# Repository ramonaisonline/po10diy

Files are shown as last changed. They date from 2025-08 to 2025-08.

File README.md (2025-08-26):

# po10diy
A tiny video synthesizer in the pocket operator format

## Background
I made this for the Teenage Engineering #po10diy contest — it's a two-color video synthesizer that has an onboard screen and battery for making video art on the go, and a DVI port so you can plug it into a projector!

You can read the full story behind it on my website: [ramona.diy](https://ramona.diy/video-art/po-video)

## Making your own
I'm not selling these, but this repository includes everything you'd need to make your own! And I encourage that! Please send me pics :)

# Hardware
## Supplies
I estimate that these cost around $100 to build. The most expensive parts of this are:
- The display ($45)
- The microcontroller ($15)
- The PCB (maybe $10-20 depending on where you get it from, how many you order, the tariffs du jour, etc).

### Parts
- 1 x [Adafruit Feather RP2040 with DVI](https://www.adafruit.com/product/5710)
- 1 x [Adafruit 2.7” 400x240 Sharp Memory Display](https://www.adafruit.com/product/4694)
- 2 x [10k potentiometer with built-in knob](https://www.adafruit.com/product/4133)
- 2 x [Breadboard-friendly 3.5mm stereo headphone jack](https://www.adafruit.com/product/1699)
- 1 x [Adafruit 400 mAh LiPo battery](https://www.adafruit.com/product/3898)
- 18 x [Surface-mount tactile switches](https://www.jameco.com/z/TL3301NF160QG-TR-JVP-Jameco-ValuePro-Surface-Mount-Tactile-Pushbutton-Switch-SPST-NO-OFF-MOM-50mA-12VDC-Tape-Reel_2334399.html)
- 18 x [Surface-mount 1N4148 diode](https://www.mouser.com/ProductDetail/Vishay/1N4148W-HG3_A-08?qs=Imq1NPwxi77PuyLGBhrVtQ%3D%3D)
- 2 x [Surface-mount 1.1k resistor](https://www.mouser.com/ProductDetail/Vishay-Beyschlag/MCS04020D1101BE000?qs=bTzheeSci6TjHr/d2PD0oQ%3D%3D)
  - R3 and R4 on the PCB
- 1 x [10.2k Surface-mount resistor](https://www.mouser.com/ProductDetail/Vishay/MCS04020D1022BE000?qs=pUKx8fyJudATYWOpd0Fc/A%3D%3D)
  - R1 on the PCB
- 1 x [15k Surface-mount resistor](https://www.mouser.com/ProductDetail/Vishay-Beyschlag/MCS04020C1502FE500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)
  - R2 on the PCB
- 2 x [15 uF Surface-mount capacitor](https://www.mouser.com/ProductDetail/Murata-Electronics/GRM155R60G156ME01D?qs=doiCPypUmgFLObzcgpnt9Q%3D%3D)
  - C1 and C2 on the PCB
- 1 x [Slide switch](https://www.mouser.com/ProductDetail/E-Switch/EGJ1210AAT2?qs=%252BXxaIXUDbq28DPumZsnIIA%3D%3D)
- Standard 0.1” header pins and sockets, specifically:
  - One 12-pin female header
  - One 12-pin male header
  - One 16-pin female header
  - One 16-pin male header
  - One 9-pin male header (for the display)
  - You can buy these in bulk (I just had a bunch lying around), or you can get some from Adafruit, like [this](https://www.adafruit.com/product/2886) and [this](https://www.adafruit.com/product/3002)
- Custom PCB
  - I've uploaded the files for these too, so you can just order them directly
  - More details below
- 4 x M2 or M2.5 10mm machine screw
- 12 x M2 or M2.5 nut

### Tools
- Soldering iron
- Lead-free solder
- Low-temp solder paste
  - I used [Maker Paste](https://www.adafruit.com/product/3217)
- Hot plate
  - I used a TLBZK 100mm x 100mm 350W hot plate from Amazon
- Ventilation fan
- Snips
- Tweezers for positioning small components
- Hobby knife or file for cleaning up rough PCB edges

## PCB
You can order the board from [my shared project on OSHPark](https://oshpark.com/shared_projects/P2hzrhho) — as of August 2025 it costs $61 for 3 copies.

If you'd prefer to order them from a different manufacturer, you can use the exported Gerber files in the PCB Files directory. I believe the existing exports will just work, but if they don't for whatever reason, I've also included the entire KiCAD project. You can find [instructions for exporting the files yourself here](https://jlcpcb.com/help/article/how-to-generate-gerber-and-drill-files-in-kicad-8) (for JLCPCB at least).

## Assembly steps

### 1. Cut or file down any rough edges on the PCB
- Mine came with little spiky protrusions from the manufacturing process, and I just snipped and filed them down

### 2. Unpackage and organize your parts
- The resistors especially are hard to tell apart, so keep everything nice and tidy and don't forget what's what!

### 3. Place the surface-mount diodes, resistors, and capcitors
- Pre-heat the hotplate according to your solder paste (I used Maker Paste and set my hotplate to 145 C)
- Squeeze out little dabs of maker paste on each of the pads for the diodes, resistors, and capacitors (we'll do the tactile switches in a separate step)
  - Some of these pads are quite small, so it can help to use a toothpick to scrape out little blobs of paste and wipe them where you want them, rather than squeezing from the tube directly onto the PCB
- Use small amounts of paste, and be especially cautious with the pads for the tiny resistors and capacitors, as they can easily form bridges when too much solder paste is used
- Use tweezers to position the diodes, resistors, and capacitors into their respective places one by one, and gently press them into the paste
  - R1 is the 10.2k resistor
  - R2 is the 15k resistor
  - R3 and R4 are the 1.1k resistors
  - The capacitors are identical but go in the spots marked C1 and C2
  - The diodes are also interchangeable but make sure the stripe on the diode is facing INTO the "C" shaped silkscreen marking, not away from it

### 4. Solder the diodes, resistors, and capacitors
- With the components all placed, put the PCB on the hotplate and let it melt the solder
- First you'll see the paste blobs spread out as the paste warms
- Then the liquid-y flux will boil off
- Then the solder balls in the paste will melt and reflow onto the pads, hopefully avoiding the solder mask
- This process takes a minute or two depending on the temperature
- Ideally you should see your components slide and adjust into place from the surface tension of the solder
- Watch carefully to make sure the solder paste is all melting at roughly the same time
  - If the board isn't sitting totally flat, press it down with a scredriver or tweezers to make sure it's heating evenly
- Look for any solder bridges that might have formed around the smallest components, and use tweezers or a craft knife to very gently remove some of the solder or smush it around until it separates again from the solder mask

### 5. Let the PCB cool
- It will be quite hot, so remove the PCB with tweezers or something similar and let it cool down and rest on a heat-safe surface
- Let it cool completely, to make the next step easier

### 6. Place the tactile switches
- Make sure the hot plate is preheating again if you shut it off earlier
- Like before, squeeze out solder blobs onto all the pads of the 18 tactile switches (though this time it will be a little easier to not make a mess since the pads are larger and further apart)
- Use tweezers to position the tactile switches on the blobs of solder paste

### 7. Solder the tactile switches
- Like before, put the PCB on the hotplate
  - I tried to have the top third of the PCB hanging off the plate so that the smaller components didn't heat up again, just in case their positioning got messed up, but I don't know how much of a difference this makes
- Wait a minute or two for the paste to melt and attach the switches

### 8. Let the PCB cool
- It's hot! Be careful!

### 9. Flip the board over and solder the 12 and 16 pin female header strips to the underside of the board
- The microcontroller will go on the back
- Strictly speaking you don't need the female header here, you could solder the feather to the circuit board directly with male header, but the female header makes it removable in case you want to use it for something else later, and it makes room for the battery to go underneath
- Trim the leads if they're long on the front side, the display will go above them and there's only so much room

### 10. Solder the 12 and 16 pin male header strips to the Feather
- The header should point "down" (i.e. the longer part should protrude from the flat bottom of the Feather), and you should be soldering it from the top of the Feather
- I like to just plug the male header into the female header we just soldered, then drop the Feather on top of that and solder — it holds everything in place!

### 11. Solder the audio jacks to the back of the board
- You may have to press quite firmly to get all five pins to slide into the holes at once, or even bend them a bit to align better

### 12. Solder the slide switch to the front of the board
- It's slim enough to fit under the display, so you can mount it on the front
- Note that when I designed the PCB I hooked up this switch backwards, so you slide it "down" / towards you to turn it on

### 13. Solder the potentiometers
- You may have to bend the side tabs in slightly to get them to align with the holes
- Double check the tilt of the potentiometers by looking at them from the side. It's easy for them to slightly lean one direction or the other.

### 14. At this point, you can test!
- Upload the code to the Feather using the procedure below to test the device with an external projector / monitor / TV and verify that the buttons and pots all work as expected
- This step is optional, but it's much easier to fix any issues with the diodes / resisotrs / capacitors now, before you solder the display on
- At a minimum, check the connections with a thorough visual inspection and maybe even with a multimeter
- Make sure there are no shorts from excess solder, and that all the components are fully and securely attached

### 15. Solder the male header to the display
- But do NOT solder it to rest of the PCB yet! That will be our final step because it depends on a few things being aligned first.

### 16. File down the right inner corner of the display to fit around Pot B
- Note that the lower mounting points of the display have a slight inner radius where they meet the main body of the display PCB
- This will bump into the hard corner of Pot B and make it hard to align the display properly
- With a craft knife or a file, you can shave down that inner corner radius to a right angle
- You may also need to file down the part of plastic casing of the potentiometers that faces the display a bit to get it to slide smoothly past them

### 17. Mount the display
- Thread bolts through the four mounting holes of the display
- If using M2 bolts, thread two nuts on each of the bolts to provide even spacing between the display and the main PCB
- If using M2.5 bolts, thread nuts only on the upper left, upper right, and lower left bolts (the nuts are too big to sit next to the pots)
- Mount the display to the main PCB using four more nuts
  - The already-soldered male header should be poking through the holes on the main PCB now

### 18. Solder the display
- Almost done! You can test it now if you Like

### 19. Install the battery
- Now, you can plug in the LiPo battery and tuck it under the feather
- It helps to secure it with a piece of tape or something like that

# Software
I've included the Arduino code that I used on my version, with all the drawing functions and everything. Feel free to modify it to your liking! I've included a template layer function in the layers.ino file along with some instructions about how to use the buttons / pot values / etc.

## Flashing the Feather
I recommend follow Adafruit's detailed setup steps:
- [Setting up the Arduino IDE for RP2040 boards](https://learn.adafruit.com/adafruit-feather-rp2040-dvi/arduino-ide-setup)
- [Loading sketches onto the Feather RP2040](https://learn.adafruit.com/adafruit-feather-rp2040-dvi/arduino-usage)
  - The Feather has a UF2 bootloader which means it should be able to put itself into a special mode where it acts as a USB drive and the Arduino IDE can just drop a file on it to load the compiled sketch -- you SHOULD be able to just click "Upload" in the Arduino IDE and it should just work
  - However, I've never gotten that to work consistently, for whatever reason
  - Instead I follow the manual bootloader steps at the bottom of that page, and it works very reliably
  - That does make it slightly more annoying to use the serial monitor because sometimes you have to switch the selected board in the Arduino IDE and close / open the serial monitor panel to get messages to come through
  - All that is to say, YMMV, and try it both ways!
- [All about the PicoDVI library for the Feather](https://learn.adafruit.com/picodvi-arduino-library-video-out-for-rp2040-boards)
- [Drawing shapes with Adafruit GFX](https://learn.adafruit.com/adafruit-gfx-graphics-library/graphics-primitives)

## Remaining TODOs
A few small features left to implement here!
- The PO Sync feature (the PCB should be set up for it)
- Creating / swapping between different sequences (the folder button)
- Switch layers without triggering them via the layer buttons
- Change tempo

# Using it
TODO: Quick user manual

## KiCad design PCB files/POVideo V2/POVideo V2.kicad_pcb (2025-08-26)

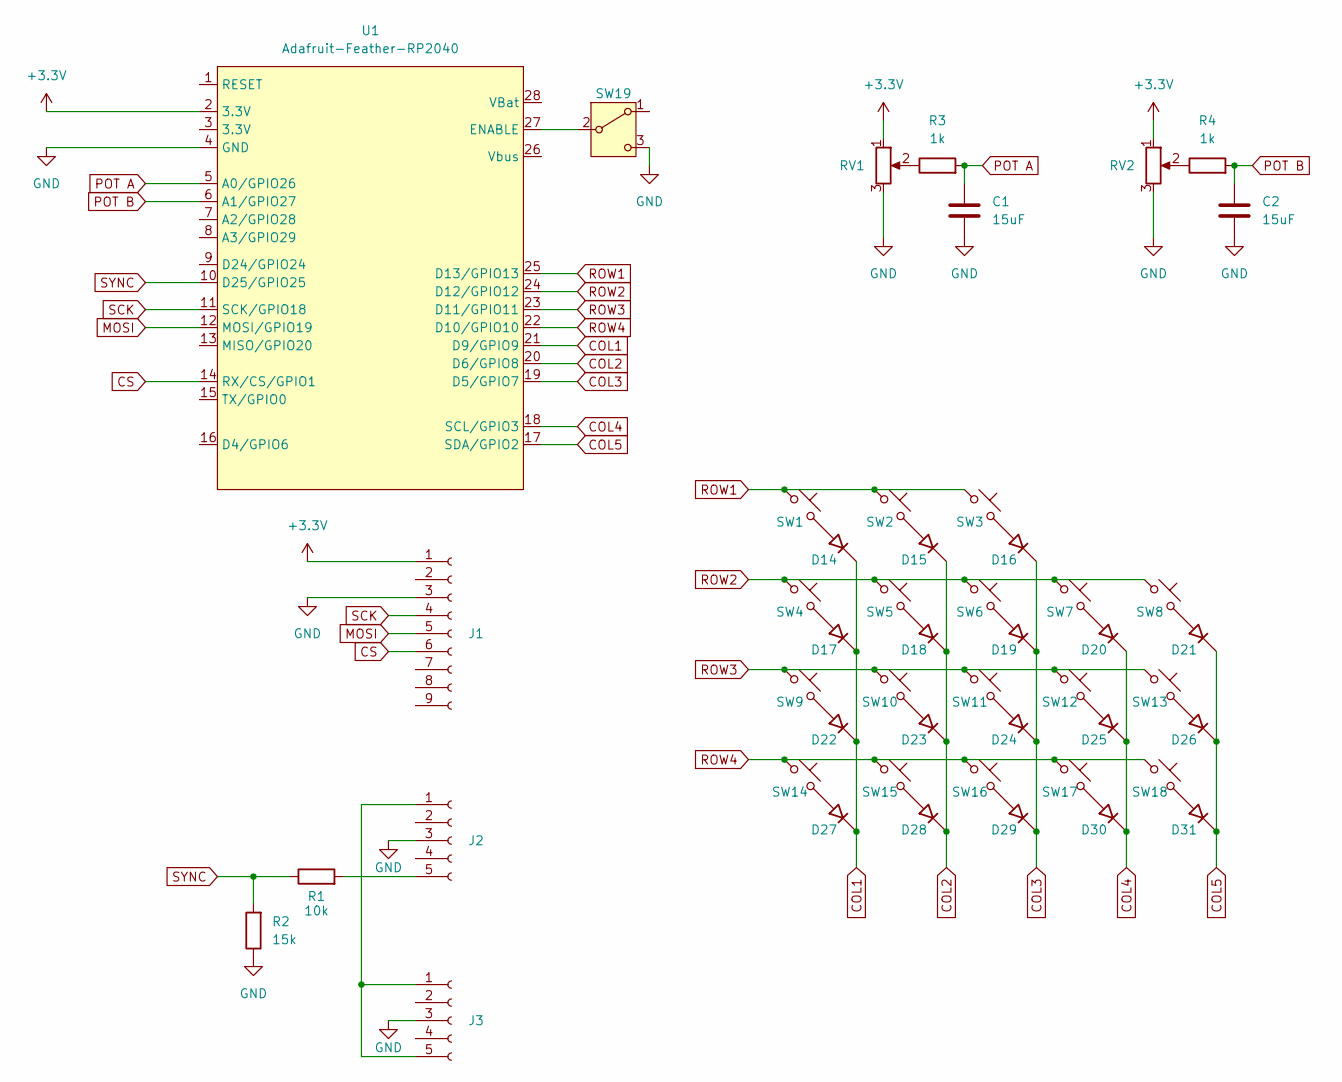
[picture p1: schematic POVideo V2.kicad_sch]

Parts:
C1, C2: 15uF; C_0402_1005Metric
D14, D15, D16, D17, D18, D19, D20, D21, D22, D23, D24, D25, D26, D27, D28, D29, D30, D31: D_45deg; D_SOD-123
J1: Conn_01x05_Socket; PinHeader_1x09_P2.54mm_Vertical
J2, J3: Conn_01x05_Socket; 5 pin headphone jack
R1: 10k; R_0402_1005Metric
R2: 15k; R_0402_1005Metric
R3, R4: 1k; R_0402_1005Metric
RV1, RV2: R_Potentiometer; Adafruit Potentiometer
SW1, SW2, SW3, SW4, SW5, SW6, SW7, SW8, SW9, SW10, SW11, SW12, SW13, SW14, SW15, SW16, SW17, SW18: SW_Push_45deg; TL3301 6mm tactile switch
SW19: SW_SPST; Right Angle Slide Switch
U1: Adafruit-Feather-RP2040; Adafruit_Feather

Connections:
+3.3V: J1.1, RV1.1, RV2.1, U1.2 (3.3V)
COL1: D14.1 (K), D17.1 (K), D22.1 (K), D27.1 (K), U1.21 (D9/GPIO9)
COL2: D15.1 (K), D18.1 (K), D23.1 (K), D28.1 (K), U1.20 (D6/GPIO8)
COL3: D16.1 (K), D19.1 (K), D24.1 (K), D29.1 (K), U1.19 (D5/GPIO7)
COL4: D20.1 (K), D25.1 (K), D30.1 (K), U1.18 (SCL/GPIO3)
COL5: D21.1 (K), D26.1 (K), D31.1 (K), U1.17 (SDA/GPIO2)
CS: J1.6, U1.14 (RX/CS/GPIO1)
GND: C1.2, C2.2, J1.3, J2.3, J3.3, R2.1, RV1.3, RV2.3, SW19.3 (C), U1.4 (GND)
LED_DATA: U1.16 (D4/GPIO6)
MOSI: J1.5, U1.12 (MOSI/GPIO19)
unnamed: D14.2 (A), SW1.2
unnamed: D15.2 (A), SW2.2
unnamed: D16.2 (A), SW3.2
unnamed: D17.2 (A), SW4.2
unnamed: D18.2 (A), SW5.2
unnamed: D19.2 (A), SW6.2
unnamed: D20.2 (A), SW7.2
unnamed: D21.2 (A), SW8.2
unnamed: D22.2 (A), SW9.2
unnamed: D23.2 (A), SW10.2
unnamed: D24.2 (A), SW11.2
unnamed: D25.2 (A), SW12.2
unnamed: D26.2 (A), SW13.2
unnamed: D27.2 (A), SW14.2
unnamed: D28.2 (A), SW15.2
unnamed: D29.2 (A), SW16.2
unnamed: D30.2 (A), SW17.2
unnamed: D31.2 (A), SW18.2
unnamed: J2.1, J3.1, J3.5
unnamed: J2.5, R1.2
unnamed: R3.1, RV1.2
unnamed: R4.1, RV2.2
unnamed: SW19.2 (B), U1.27 (ENABLE)
POT A: C1.1, R3.2, U1.5 (A0/GPIO26)
POT B: C2.1, R4.2, U1.6 (A1/GPIO27)
ROW1: SW1.1, SW2.1, SW3.1, U1.25 (D13/GPIO13)
ROW2: SW4.1, SW5.1, SW6.1, SW7.1, SW8.1, U1.24 (D12/GPIO12)
ROW3: SW9.1, SW10.1, SW11.1, SW12.1, SW13.1, U1.23 (D11/GPIO11)
ROW4: SW14.1, SW15.1, SW16.1, SW17.1, SW18.1, U1.22 (D10/GPIO10)
SCK: J1.4, U1.11 (SCK/GPIO18)
SYNC: R1.1, R2.2, U1.10 (D25/GPIO25)

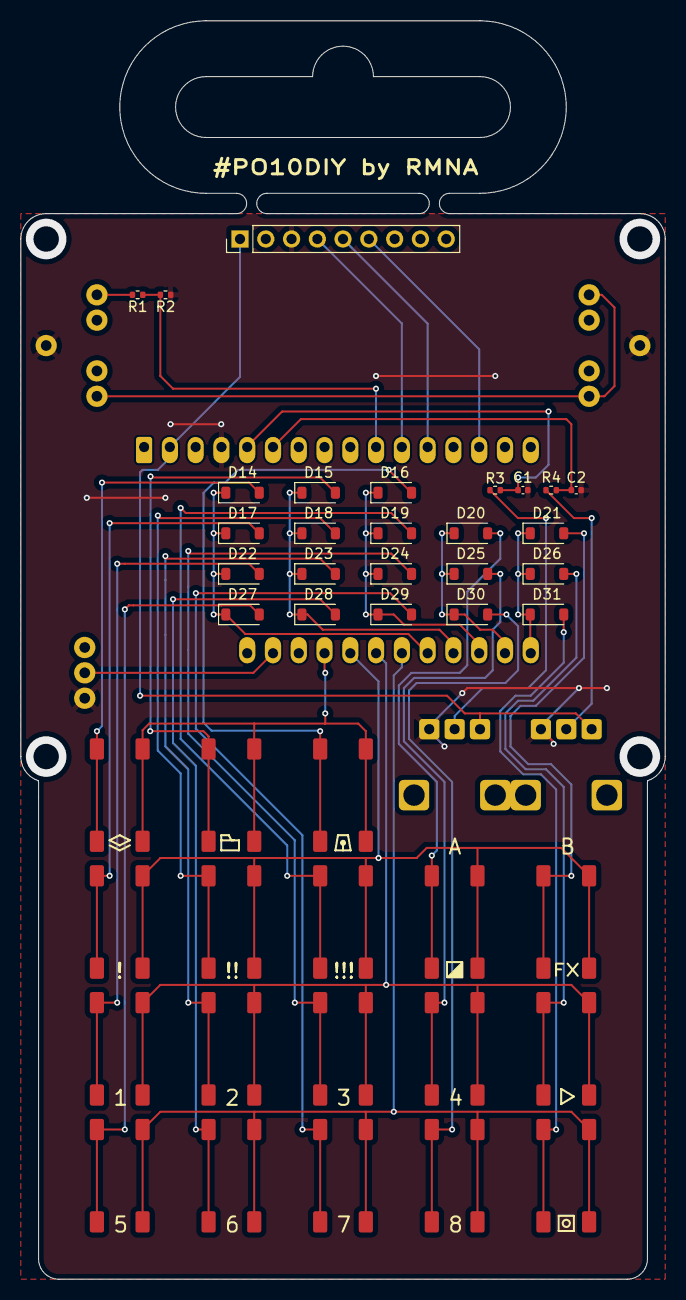
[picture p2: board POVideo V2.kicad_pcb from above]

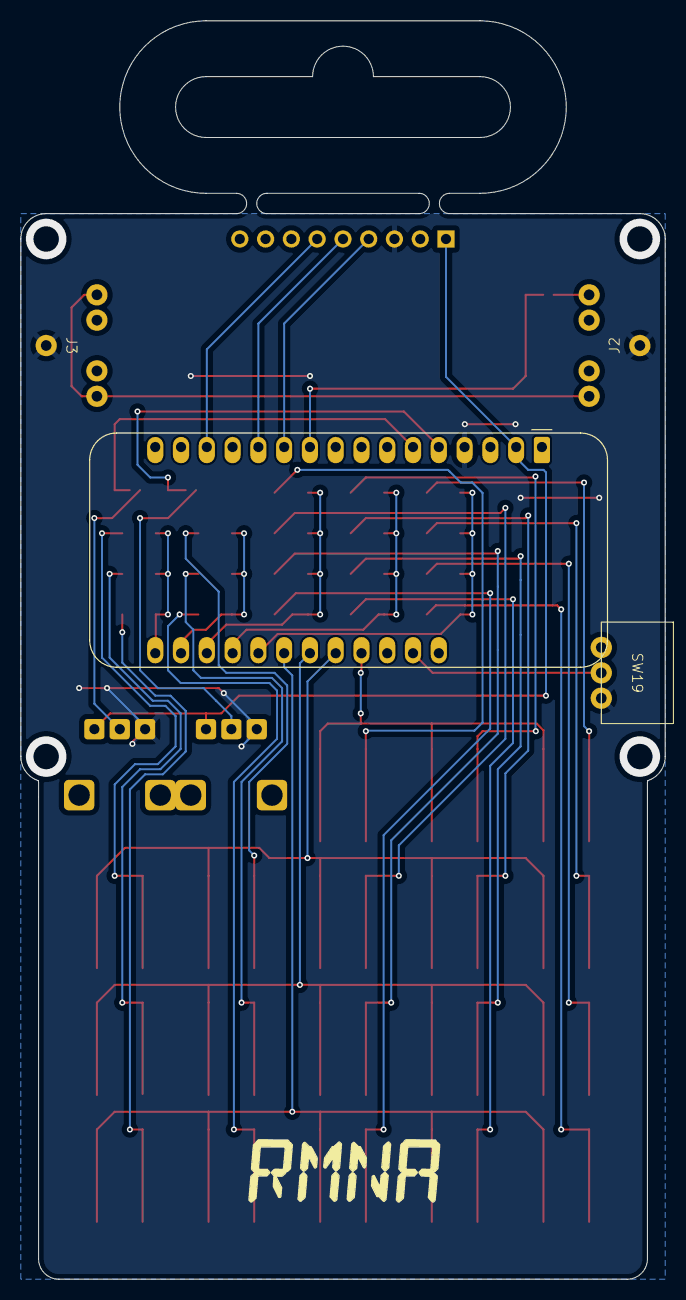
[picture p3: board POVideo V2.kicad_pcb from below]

Board: 2 copper layers, 63.5 x 124.0 mm, 49 parts (4 on the bottom side), 40 nets.

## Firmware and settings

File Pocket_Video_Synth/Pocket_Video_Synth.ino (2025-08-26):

// POCKET VIDEO SYNTHESIZER by Ramona Sharples aka RMNA
// A pocket-sized two-color video toy based on the Adafruit Feather RP2040 with DVI
// Find instructions and PCB files at https://github.com/ramonaisonline/po10diy
// This is a video synthesizer homage to Teenage Engineering's Pocket Operator synthesizers
// Originally built for the #PO10DIY contest
// Infinite gratitude to Adafruit for wonderful libraries and example code

#include <Adafruit_GFX.h>
#include <Adafruit_SharpMem.h>
#include <PicoDVI.h>
#include <math.h>
#include <Arduino.h>
#include "Adafruit_Keypad.h"

#define TWOPI 2 * M_PI

#define SHARP_SCK  13
#define SHARP_MOSI 11
#define SHARP_SS   1

#define POT_A_PIN A0
#define POT_B_PIN A1

// Initialize the onboard Sharp Memory Display
// The 3000000 param at the end configures the SPI to run at 3MHz.
// The default is 2MHz, and this seems to get slightly better refresh rates
// without any issues in my experience.
Adafruit_SharpMem display(&SPI, SHARP_SS, 400, 240, 3000000);

// This initializes the DVI output as 8-bit color 320x240 
// (it gets pixel-doubled to 480p)
// I wanted this to be a DVIGFX1 1-bit display object, but that only seems 
// to support the full 640x480 framebuffer, and I wanted to match the
// resolution of the sharp display as much as possible.
DVIGFX8 dvidisplay(DVI_RES_320x240p60, true, adafruit_feather_dvi_cfg);

#define BLACK 0
#define WHITE 1

// Display dimensions
#define DISPLAY_WIDTH  400
#define DISPLAY_HEIGHT 240

// Handy shortcuts for "Full Width", "Canvas Width", and "Height"
// e.g. the center of onboard display is [FW/2, H/2]
//  and the center of the DVI output is [CW/2, H/2]
// The middle 320 horizontal pixels of the onboard display
// are also used as a canvas, hence the name
#define FW 400
#define CW 320
#define H 240

#define HALFFW 200
#define HALFCW 160
#define HALFH 120

// The left and right 40 horizontal pixels on the onboard display
// are reserved for bits of UI, so the canvas has a 40px offset
#define CX0 40
#define CY0 0

// Calculate buffer size for 1-bit depth frame buffer
// Each byte stores 8 pixels, so we need (WIDTH * HEIGHT + 7) / 8 bytes
#define BUFFER_SIZE ((FW * H + 7) / 8)

#define ROWS 4 // rows of buttons
#define COLS 5 // columns of buttons


// These are bitmap UI elements stored in program memory
// to save the somewhat scarce RAM

// 'Play Off', 14x14px
const unsigned char epd_bitmap_Play_Off [] PROGMEM = {
	0x00, 0x00, 0x00, 0x00, 0x00, 0x00, 0x18, 0x00, 0x16, 0x00, 0x11, 0x80, 0x10, 0x60, 0x10, 0x60, 
	0x11, 0x80, 0x16, 0x00, 0x18, 0x00, 0x00, 0x00, 0x00, 0x00, 0x00, 0x00
};
// 'Play On', 14x14px
const unsigned char epd_bitmap_Play_On [] PROGMEM = {
	0x7f, 0xf8, 0xff, 0xfc, 0xff, 0xfc, 0xe7, 0xfc, 0xe1, 0xfc, 0xe0, 0x7c, 0xe0, 0x1c, 0xe0, 0x1c, 
	0xe0, 0x7c, 0xe1, 0xfc, 0xe7, 0xfc, 0xff, 0xfc, 0xff, 0xfc, 0x7f, 0xf8
};
// 'Record Off', 14x14px
const unsigned char epd_bitmap_Record_Off [] PROGMEM = {
	0x00, 0x00, 0x00, 0x00, 0x00, 0x00, 0x07, 0x80, 0x08, 0x40, 0x10, 0x20, 0x10, 0x20, 0x10, 0x20, 
	0x10, 0x20, 0x08, 0x40, 0x07, 0x80, 0x00, 0x00, 0x00, 0x00, 0x00, 0x00
};
// 'Record On', 14x14px
const unsigned char epd_bitmap_Record_On [] PROGMEM = {
	0x7f, 0xf8, 0xff, 0xfc, 0xff, 0xfc, 0xf8, 0x7c, 0xf0, 0x3c, 0xe0, 0x1c, 0xe0, 0x1c, 0xe0, 0x1c, 
	0xe0, 0x1c, 0xf0, 0x3c, 0xf8, 0x7c, 0xff, 0xfc, 0xff, 0xfc, 0x7f, 0xf8
};
// 'Tempo Disco', 36x15px
const unsigned char epd_bitmap_Tempo_Disco [] PROGMEM = {
	0xff, 0xff, 0xff, 0xff, 0xf0, 0x80, 0x00, 0x00, 0x00, 0x10, 0xbf, 0xff, 0xff, 0xff, 0xd0, 0xa3, 
	0x0c, 0xe3, 0x3f, 0xd0, 0xad, 0xbb, 0x5e, 0xdf, 0xd0, 0xad, 0xbb, 0xde, 0xdf, 0xd0, 0xad, 0xbb, 
	0xde, 0xdf, 0xd0, 0xad, 0xbc, 0xde, 0xdf, 0xd0, 0xad, 0xbf, 0x5e, 0xdf, 0xd0, 0xad, 0xbf, 0x5e, 
	0xdf, 0xd0, 0xad, 0xbb, 0x5e, 0xdf, 0xd0, 0xa3, 0x0c, 0xe3, 0x3f, 0xd0, 0xbf, 0xff, 0xff, 0xff, 
	0xd0, 0x80, 0x00, 0x00, 0x00, 0x10, 0xff, 0xff, 0xff, 0xff, 0xf0
};
// 'Tempo Hiphop', 36x15px
const unsigned char epd_bitmap_Tempo_Hiphop [] PROGMEM = {
	0xff, 0xff, 0xff, 0xff, 0xf0, 0x80, 0x00, 0x00, 0x00, 0x10, 0xbf, 0xff, 0xff, 0xff, 0xd0, 0xad, 
	0x08, 0xdb, 0x31, 0xd0, 0xad, 0xbb, 0x5a, 0xd6, 0xd0, 0xad, 0xbb, 0x5a, 0xd6, 0xd0, 0xa1, 0xb8, 
	0xc2, 0xd1, 0xd0, 0xad, 0xbb, 0xda, 0xd7, 0xd0, 0xad, 0xbb, 0xda, 0xd7, 0xd0, 0xad, 0xbb, 0xda, 
	0xd7, 0xd0, 0xad, 0xbb, 0xda, 0xd7, 0xd0, 0xad, 0x0b, 0xdb, 0x37, 0xd0, 0xbf, 0xff, 0xff, 0xff, 
	0xd0, 0x80, 0x00, 0x00, 0x00, 0x10, 0xff, 0xff, 0xff, 0xff, 0xf0
};
// 'Tempo Techno', 36x15px
const unsigned char epd_bitmap_Tempo_Techno [] PROGMEM = {
	0xff, 0xff, 0xff, 0xff, 0xf0, 0x80, 0x00, 0x00, 0x00, 0x10, 0xbf, 0xff, 0xff, 0xff, 0xd0, 0xa1, 
	0x8c, 0x5a, 0xd9, 0xd0, 0xb7, 0x7b, 0xda, 0x56, 0xd0, 0xb7, 0x7b, 0xda, 0x96, 0xd0, 0xb7, 0x7b, 
	0xc2, 0x96, 0xd0, 0xb7, 0x0b, 0xda, 0xd6, 0xd0, 0xb7, 0x7b, 0xda, 0xd6, 0xd0, 0xb7, 0x7b, 0xda, 
	0xd6, 0xd0, 0xb7, 0x7b, 0xda, 0xd6, 0xd0, 0xb7, 0x8c, 0x5a, 0xd9, 0xd0, 0xbf, 0xff, 0xff, 0xff, 
	0xd0, 0x80, 0x00, 0x00, 0x00, 0x10, 0xff, 0xff, 0xff, 0xff, 0xf0
};
// 'Layer 08', 24x16px
const unsigned char epd_bitmap_Layer_08 [] PROGMEM = {
	0xff, 0xff, 0xff, 0x80, 0x00, 0x01, 0x80, 0x00, 0x01, 0x80, 0x00, 0x01, 0x80, 0x00, 0x01, 0x80, 
	0x00, 0x01, 0x80, 0x00, 0x01, 0x86, 0xdb, 0x61, 0x86, 0xdb, 0x61, 0x80, 0x00, 0x01, 0x80, 0x00, 
	0x01, 0x80, 0x00, 0x01, 0x80, 0x00, 0x01, 0x80, 0x00, 0x01, 0x80, 0x00, 0x01, 0xff, 0xff, 0xff
};
// 'Layer 07', 24x16px
const unsigned char epd_bitmap_Layer_07 [] PROGMEM = {
	0xff, 0xff, 0xff, 0x80, 0x00, 0x01, 0x80, 0x07, 0x81, 0x80, 0x18, 0x61, 0x81, 0xf0, 0x11, 0x82, 
	0x30, 0x11, 0x84, 0x48, 0x09, 0x84, 0x48, 0x09, 0x84, 0x48, 0x09, 0x84, 0x48, 0x09, 0x82, 0x30, 
	0x11, 0x81, 0xf0, 0x11, 0x80, 0x18, 0x61, 0x80, 0x07, 0x81, 0x80, 0x00, 0x01, 0xff, 0xff, 0xff
};
// 'Layer 02', 24x16px
const unsigned char epd_bitmap_Layer_02 [] PROGMEM = {
	0xff, 0xff, 0xff, 0x80, 0x00, 0x01, 0x83, 0xe7, 0xc1, 0x82, 0x24, 0x41, 0x82, 0x27, 0xc1, 0x82, 
	0x20, 0x01, 0x82, 0x27, 0xc1, 0x82, 0x24, 0x41, 0x82, 0x24, 0x41, 0x83, 0xe4, 0x41, 0x80, 0x04, 
	0x41, 0x83, 0xe4, 0x41, 0x82, 0x24, 0x41, 0x83, 0xe7, 0xc1, 0x80, 0x00, 0x01, 0xff, 0xff, 0xff
};
// 'Layer 05', 24x16px
const unsigned char epd_bitmap_Layer_05 [] PROGMEM = {
	0xff, 0xff, 0xff, 0x80, 0x00, 0x01, 0x80, 0x00, 0x01, 0x80, 0x00, 0x01, 0x80, 0x01, 0x81, 0x80, 
	0x1f, 0x81, 0x80, 0xe1, 0x01, 0x87, 0x01, 0x01, 0x81, 0x03, 0x01, 0x80, 0xc2, 0x01, 0x80, 0x22, 
	0x01, 0x80, 0x1c, 0x01, 0x80, 0x04, 0x01, 0x80, 0x00, 0x01, 0x80, 0x00, 0x01, 0xff, 0xff, 0xff
};
// 'Layer 04', 24x16px
const unsigned char epd_bitmap_Layer_04 [] PROGMEM = {
	0xff, 0xff, 0xff, 0x80, 0x00, 0x01, 0x80, 0x00, 0x01, 0x80, 0x07, 0x81, 0x81, 0xe8, 0x41, 0x82, 
	0x30, 0x21, 0x84, 0x50, 0x21, 0x84, 0x90, 0x21, 0x84, 0x90, 0x21, 0x84, 0x88, 0x41, 0x82, 0x87, 
	0x81, 0x81, 0xc2, 0x01, 0x80, 0x3c, 0x01, 0x80, 0x00, 0x01, 0x80, 0x00, 0x01, 0xff, 0xff, 0xff
};
// 'Layer 06', 24x16px
const unsigned char epd_bitmap_Layer_06 [] PROGMEM = {
	0xff, 0xff, 0xff, 0x80, 0x00, 0x01, 0x80, 0x00, 0x01, 0x8f, 0xff, 0xf1, 0x89, 0x24, 0x91, 0x89, 
	0x24, 0x91, 0x8f, 0xff, 0xf1, 0x89, 0x24, 0x91, 0x89, 0x24, 0x91, 0x8f, 0xff, 0xf1, 0x89, 0x24, 
	0x91, 0x89, 0x24, 0x91, 0x8f, 0xff, 0xf1, 0x80, 0x00, 0x01, 0x80, 0x00, 0x01, 0xff, 0xff, 0xff
};
// 'Layer 03', 24x16px
const unsigned char epd_bitmap_Layer_03 [] PROGMEM = {
	0xff, 0xff, 0xff, 0x80, 0x00, 0x01, 0x80, 0x00, 0x01, 0x82, 0xbf, 0xc1, 0x82, 0xa0, 0x01, 0x82, 
	0xbd, 0x41, 0x82, 0xa1, 0x41, 0x82, 0xb5, 0x41, 0x82, 0x05, 0x41, 0x82, 0xf5, 0x41, 0x80, 0x00, 
	0x01, 0x83, 0xbf, 0xc1, 0x82, 0xa0, 0x41, 0x80, 0x00, 0x01, 0x80, 0x00, 0x01, 0xff, 0xff, 0xff
};
// 'Layer 01', 24x16px
const unsigned char epd_bitmap_Layer_01 [] PROGMEM = {
	0xff, 0xff, 0xff, 0x80, 0x00, 0x01, 0x80, 0x00, 0x01, 0x81, 0xff, 0xf1, 0x80, 0x00, 0x01, 0x9f, 
	0xfc, 0x01, 0x80, 0x00, 0x01, 0x80, 0x3f, 0xf9, 0x80, 0x00, 0x01, 0x81, 0xff, 0xc1, 0x80, 0x00, 
	0x01, 0x9f, 0xff, 0x81, 0x80, 0x00, 0x01, 0x80, 0x00, 0x01, 0x80, 0x00, 0x01, 0xff, 0xff, 0xff
};

// Array of all bitmaps for convenience. (Total bytes used to store images in PROGMEM = 992)
const int epd_bitmap_allArray_LEN = 15;
const unsigned char* epd_bitmap_allArray[15] = {
	epd_bitmap_Layer_01,
	epd_bitmap_Layer_02,
	epd_bitmap_Layer_03,
	epd_bitmap_Layer_04,
	epd_bitmap_Layer_05,
	epd_bitmap_Layer_06,
	epd_bitmap_Layer_07,
	epd_bitmap_Layer_08,
	epd_bitmap_Play_Off,
	epd_bitmap_Play_On,
	epd_bitmap_Record_Off,
	epd_bitmap_Record_On,
	epd_bitmap_Tempo_Disco,
	epd_bitmap_Tempo_Hiphop,
	epd_bitmap_Tempo_Techno
};



// Set up keypad
// This is based on Adafruit's example code for their keypad library
char keys[ROWS][COLS] = {
  {'X','Y','Z','-','-'},
  {'A','B','C','D','F'},
  {'1','2','3','4','P'},
  {'5','6','7','8','W'}
};
uint8_t rowPins[ROWS] = {13, 12, 11, 10}; // connect to the row pinouts of the keypad
uint8_t colPins[COLS] = {9, 6, 5, 3, 2};  // connect to the col pinouts of the keypad
long keypressTimes[30] = {0};
int longPressThreshold = 300; // ms
bool fxHeld = false;

Adafruit_Keypad keypad = Adafruit_Keypad( makeKeymap(keys), rowPins, colPins, ROWS, COLS);


// Sequencer setup
// The values of each knob, the !/!!/!!! variant, and the B/W color is saved
// For each layer at each of the 8 steps in the sequence
const int STEPS = 8;
const int LAYERS = 8;
const int PARAMS = 4; //A, B, Type, Color
const int TOTAL_VALUES = STEPS * LAYERS * PARAMS;
uint16_t sequenceParams[TOTAL_VALUES];
// Non-sequenced values are also stoerd as "punch-in" values
// so that different layers can have different colors, etc.
uint16_t punchParams[LAYERS * PARAMS]; 

// Bitmask tracking which layers are active on each step
// Layer 0 = LSB = top left key #1, Layer 7 = MSB = bottom right key #8
uint8_t activeLayersPerStep[8];

// Bitmask tracking which layer keys are being punched in
uint8_t punchedInLayers = 0;

// Sequencer status
bool writing = false;
bool playing = false;
bool fxActive = false;
int selectedFX = 0;
int activeStep = 0;

int selectedLayer = 0; // -1 = no layer selected
uint16_t layerInitStatus = ~(uint16_t)0;

// TODO: Make the BPM toggleable
int BPM = 140;
int stepIntervalMS = 429;
long nextStepTime = 0;

// 16ms = ~60Hz reads
int potIntervalMS = 16;
long nextPotUpdateTime = 0;
int actualPotA = 0;
int actualPotB = 0;

// Track different knob values per layer 
// so it doesn't jump right away when you switch layers
int potA[LAYERS];
int potB[LAYERS];


void setup(void)
{
  // Serial.begin(115200);

  // start & clear the display
  display.begin();
  // Serial.println("Began display!");
  display.clearDisplay();
  display.cp437(true);
  display.fillRect(0, 0, FW, H, BLACK);
  // Serial.println("Cleared display!");
  
  // Start the keypad
  keypad.begin();


  if (!dvidisplay.begin()) { // Blink LED if insufficient RAM
    pinMode(LED_BUILTIN, OUTPUT);
    for (;;) digitalWrite(LED_BUILTIN, (millis() / 500) & 1);
  }
  dvidisplay.cp437(true);

  // The 8-bit mode allows for 256 slots for 16-bit colors
  // The slots start out all black 0x0000
  // Slot 0 is always used for black
  // This sets Slot 1 and Slot 255 to white
  // So you can think of pixels as 0 or 1/255, whichever is easier
  dvidisplay.setColor(1, 0xFFFF);
  dvidisplay.setColor(255, 0xFFFF);
  dvidisplay.swap(false, true); // Copy palette to the other framebuffer

  nextStepTime = millis() + stepIntervalMS;
}

void loop(void) 
{
  // Serial.println("Loop");

  // Advance the current sequencer step if need be
  // TODO use the Pocket Operator sync signal to advance steps if it's available
  if (playing == true) {
    if (millis() > nextStepTime) {
      activeStep = (activeStep + 1) % 8;
      nextStepTime = millis() + stepIntervalMS;
    }
  }

  // Read the potentiometers
  if (millis() > nextPotUpdateTime) {
    updatePots();
    nextPotUpdateTime = millis() + potIntervalMS;
  }

  // Check any keypad updates
  keypad.tick();
  handleKeypad();


  // DRAW!
  // Go through the sequencer bitmask for the current step
  // and check if any layers should be drawn here.
  // Alternatively, the user may be just holding down / "punching in" a layer.
  // If so, draw each one in turn.
  // If you want to customize your video synth, this is a great place to tinker!
  // Try swapping these out for custom drawing functions.
  for (int i = 0; i < LAYERS; i++) {
    if ((playing && isLayerActive(activeStep, i)) || isLayerPunched(i)) {
      switch (i) {
        case 0:
          randomLines();
          break;
        case 1:
          randomRect();
          break;
        case 2:
          glyphs();
          break;
        case 3:
          doodles();
          break;
        case 4:
          triangles();
          break;
        case 5:
          grid();
          break;
        case 6:
          circles();
          break;
        case 7:
          dust();
          break;
        default:
          break;
      }
    }
  }

  // If the user is holding the FX button and has selected an effect
  // apply one of these effects after completing the drawing above
  if (fxActive) {
    switch(selectedFX) {
      case 0:
        fillBlack();
        break;
      case 1:
        fillWhite();
        break;
      case 2:
        invert();
        break;
      case 3:
        fgColor();
        break;
      case 4:
        reflectHorizontally();
        break;
      case 5:
        reflectVertically();
        break;
      case 6:
        reflectBoth();
        break;
      case 7:
        bgColor();
        break;
      default:
        break;
    }
  }

  // Now draw the UI elements on the left and right sides of the onboard displays
  // Do this last to cover up any errant shapes that might bleed into this area
  drawUI();

  // Finally, refresh the onboard display
  // And swap the active framebuffer of the DVI display
  display.refresh();
  dvidisplay.swap(true, false);
}


// Convert a BPM to the approximate interval between steps at that BPM
int BPMToIntervalInMS(int bpm) {
  return 60000/bpm;
}

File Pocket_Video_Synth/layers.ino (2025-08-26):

// These are the drawing functions that are activated by buttons 1-8
// Try editing these or writing some of your own!

// IMPORTANT TO KNOW!
// You'll notice that these functions all start with a similar 16-line block
// The l variable is a shorthand for *which button this layer is mapped to*
// which ALSO affects where in the sequence memory the data for this layer is stored
// So...
// IF YOU WANT TO CHANGE WHICH BUTTONS ACTIVATE THESE LAYERS,
// YOU MUST SET l TO THE SAME NUMBER AS THE CASE THAT TRIGGERS THE LAYER IN THE 
// SWITCH STATEMENT IN THE DRAWING FUNCTION OF THE MAIN LOOP

// Sorry for yelling but I messed this up several times in my own work and it was very confusing!

// The rest of that block loads up the parameters that were stored 
// in the sequence or saved from the last punch-in and puts them in
// some convenient variables for you to use in your drawing function!

// a is the value of knob a
// b is the value of knob b
// by default these values are in the range 0-1023
// but most of the time you'll probably be mapping them to some other range of values
// using the stock map() function, or the custom cyclicalMap() function

// type is either 0, 1, or 2
// and can be used to change some mode or something within your layer

// c1 is the dominant color of your layer, either white or black (e.g. the fill color of a circle)
// c2 is whatever the opposite color is (e.g. the stroke color of a circle)

// The drawing functions used here (e.g. "drawCircle()") are defined in helpers.ino
// Basically they just wrap the drawing functions for the internal and external displays
// and duplicate every drawing command to both screens. It works well enough!

// Anyway here's a template for you!

void myCustomLayer() {
  int l = 0;                      // Set this to the number of the button you want to use
  int a, b, type, c1, c2;         // This is the list of inputs you can use to draw with
  if (isLayerPunched(l)) {        // Ignore from here...
    a = getPunchParam(l, 0);
    b = getPunchParam(l, 1);
    type = getPunchParam(l, 2);
    c1 = !getPunchParam(l, 3);
    c2 = !c1;
  }
  else {
    a = getActiveParam(l, 0);
    b = getActiveParam(l, 1);
    type = getActiveParam(l, 2);
    c1 = !getActiveParam(l, 3);
    c2 = !c1;
  }                               // ...to here

  // Maybe you'll define some variables here?
  int r = simpleMap(a, 10, 50);
  int x = cyclicalMap(b, 3, 0, 0, CW);
  int y = cyclicalMap(b, 7, 0.25, 0, H);

  if (type == 0) {
    // Draw some stuff
    drawCircle(x, y, r, c1);
    fillCircle(x, y, r, c2);
  }
  else if (type == 1) {
    // Draw some slightly different stuff
  }
  else if (type == 2) {
    // Draw some even more different stuff
  }
}

// Stock layer functions:

void randomLines() {
  int l = 0;
  int a, b, type, c1, c2;
  if (isLayerPunched(l)) {
    a = getPunchParam(l, 0);
    b = getPunchParam(l, 1);
    type = getPunchParam(l, 2);
    c1 = !getPunchParam(l, 3);
    c2 = !c1;
  }
  else {
    a = getActiveParam(l, 0);
    b = getActiveParam(l, 1);
    type = getActiveParam(l, 2);
    c1 = !getActiveParam(l, 3);
    c2 = !c1;
  }

  int length = cyclicalMap(a, 2, 0, 4, CW);
  int num = map(b, 1023, 0, 1, 50);

  if (type == 0) {
    for (int i = 0; i < num; i++) {
      // Either horizontal or vertical, plus count + length
      int x0, y0, x1, y1;
      if (a < 512) {
        x0 = random(CW - length);
        y0 = random(H);
        x1 = x0 + length;
        y1 = y0;
      }
      else {
        x0 = random(CW);
        y0 = random(H - length);
        x1 = x0;
        y1 = y0 + length;
      }
      
      drawLine(x0, y0, x1, y1, c1);
    }
  }
  else if (type == 1) {
    for (int i = 0; i < num; i++) {
      int x0 = random(CW);
      int y0 = random(H);
      int dx = random(length) * 2 - length;
      int dy = 0;
      if (x0 % 2 == 0) {
        dy = dx * -1;
      }
      else {
        dy = dx;
      }
      int x1 = x0 + dx;
      int y1 = y0 + dy;
      drawLine(x0, y0, x1, y1, c1);
      // randomLines();
    }
  }
  else if (type == 2) {
    int config = map(a, 1023, 0, 0, 5);
    int x0, y0, x1, y1, l, dx, dy;
    float theta;
    for (int i = 0; i < num; i++) {
      if (config == 0) {
        x0 = HALFCW;
        y0 = HALFH;
        theta = random(360) / 360.0 * TWOPI;
        l = random(200);
      }
      else if (config == 1) {
        if (random(2) > 0) {
          x0 = HALFCW;
          y0 = 0;
          theta = (random(180)) / 360.0 * TWOPI;
        }
        else {
          x0 = HALFCW;
          y0 = H-1;
          theta = (random(180)+180) / 360.0 * TWOPI;
        }
        l = random(288);
      }
      else if (config == 2) {
        if (random(2) > 0) {
          x0 = CW-1;
          y0 = 0;
          theta = (random(90)+90) / 360.0 * TWOPI;
        }
        else {
          x0 = 0;
          y0 = H-1;
          theta = (random(90)+270) / 360.0 * TWOPI;
        }
        l = random(400);
      }
      else if (config == 3) {
        if (random(2) > 0) {
          x0 = CW-1;
          y0 = HALFH;
          theta = (random(180)+90) / 360.0 * TWOPI;
        }
        else {
          x0 = 0;
          y0 = HALFH;
          theta = (random(180)-90) / 360.0 * TWOPI;
        }
        l = random(340);
      }
      else if (config >= 4) {
        if (random(2) > 0) {
          x0 = 0;
          y0 = 0;
          theta = (random(90)) / 360.0 * TWOPI;
        }
        else {
          x0 = CW-1;
          y0 = H-1;
          theta = (random(90)+180) / 360.0 * TWOPI;
        }
        l = random(400);
      }

      l = random(200);
      dx = cos(theta) * l;
      dy = sin(theta) * l;
      x1 = x0 + dx;
      y1 = y0 + dy;

      drawLine(x0, y0, x1, y1, c1);
    }
  }
  
}
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

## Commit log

2025-08-14 Added some assembly steps to the readme
2025-08-14 First draft of assembly steps
2025-08-26 Add arduino files
2025-08-26 README updates to finish assembly instructions and add instructions about uploading sketches
2025-08-26 Add KiCAD project and exported gerbers
    [POVideo V2-B_Cu.gbl, POVideo V2-B_Mask.gbs, POVideo V2-B_Paste.gbp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]
2025-08-26 Add notes about PCB
